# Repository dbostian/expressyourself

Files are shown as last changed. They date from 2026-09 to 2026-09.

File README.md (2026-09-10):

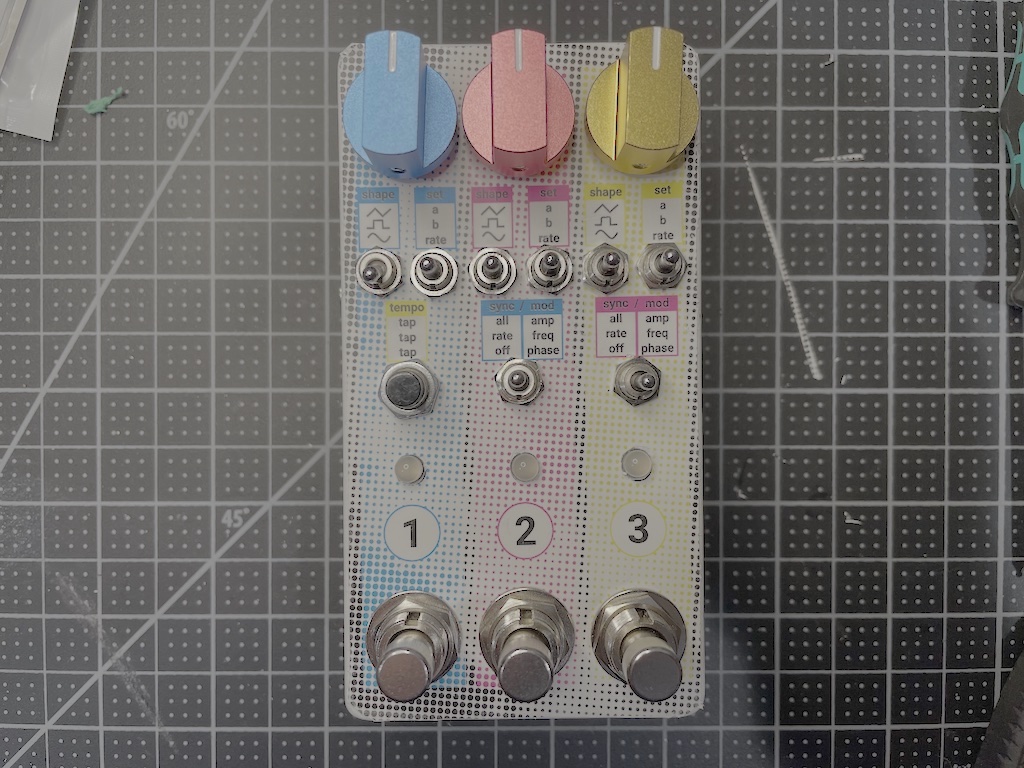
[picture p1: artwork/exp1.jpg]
pedal top view


# express yourself

A DIY triple expression pedal. This pedal was heavily inspired by the Old Blood Noise Endeavors Expression Ramper x3. I wanted to add the ability for the pedal to modulate its own values. It has three expression outputs that can sync with each other, and affect each other in weird ways.

This project is work in progress, and is released on an as-is basis. This repository contains all code, artwork (I printed a vinyl sticker), pcb schematics, gerbers, a bom, as well as 3d printing files (stls, f3d, step) for a 3d printed enclosure. The pedal will fit in a 125b enclosure. The code is working as described below/shown in the videos, but is in a preliminary stage and may contain bugs. In short, use at your own risk.

I am not planning to release detailed build instructions, but if you're a steady hand at soldering, have built a few diy pedals before, ordered custom pcbs, sourced a bom, and have flashed an arduino or two, you should be able to handle this.

Overview Video: https://www.youtube.com/watch?v=8aHI_HfOTI8
Followup Video: https://www.youtube.com/watch?v=umGa9XkKtoM
Part 3: https://www.youtube.com/watch?v=ajVojKqwqVI

## basic usage

The pedal has three sets of expression controls, arranged in columns from left to right. For any exp, you can set the wave **shape** (triangle, square or sine), an **a** value and a **b** value, and a **rate**. The exp will oscillate between **a** and **b** at the **rate** you set, using the selected **shape**. All knob settings are relative - the knob may not match the value when changing the **set** switch, so turning the knob will raise or lower the value accordingly. Pay attention to the LED's brightness, as it reflects the actual value.

Exp 1 can also have its **rate** determined by tap tempo. At most, the last five taps will be used.

To enable an exp's jack, tap the footswitch to enable it. The LED will turn white. Tap again to turn it off. The output of a jack is:
* A if the set switch is on **a**
* B if the set switch is on **b**
* Oscillating if the set switch is on **rate** and the exp is **on**
* A if the set switch is on **rate** and the exp is **off**

You can sync exp2 and exp3 the exp to their left. If **sync** is set to **rate**, the **rate** value will be copied over. If set to **all**, the **a** and **b** values will be copied as well. When syncing (**rate** or **all**), changing the **rate** value will adjust the local rate in multiples of the exp to the left - 1/8, 1/4, 1/2, 1x, 2x, 3x, or 4x.

If you hold down any footswitch while changing the **sync** switch, the exp will enter **mod** mode. The output of the exp to the left will control an aspect of this exp. as follows:
* In **amp** mod mode, the amplitude of the wave will be changed by the output of the exp to the left. **a** and **b** will move apart or closer together about their midpoint. 0% touching, 50% original values, 100% twice as far apart.
* In **freq** mod mode, the frequency of the wave will be changed. The **rate** value will be replaced with the output of exp to the left.
* In **phase** mod mode, the phase of the wave will be offset by the value of the exp to the left. 0%: minus one half wavelength, 50%: no change, 100%: plus one half wavelength.

In **amp** mod mode, the value may exceed the maximum or minimum value of the pedal. In this case, **wavefolding** will occur.

Changing the **sync** switch without holding a footswitch down will turn off the **mod** mode. You can have **sync** mode and **mod** mode active at the same time: move the **sync** switch to the desired **sync** mode, hold the foot switch and select the desired **mod** mode. You cannot have more than one **sync** mode or **mod** mode active at the same time.

If you change the **shape** switch while holding a foot switch, you will enter **random** mode - each time the wave completes a cycle, random values for **a** and **b** will be chosen, using values between the original **a** and **b**.

Future features and code changes:
* One-shot mode. Holding the tap tempo button while selecting shape will put it into one-shot mode. The EXP will move from A to B when the footswitch is tapped, and back from B to A again when tapped again, and so on.
* Hold to pause. While a footswitch is held, the exp's output and progress will be paused. It will resume when the footswitch is released.
* USB Midi?

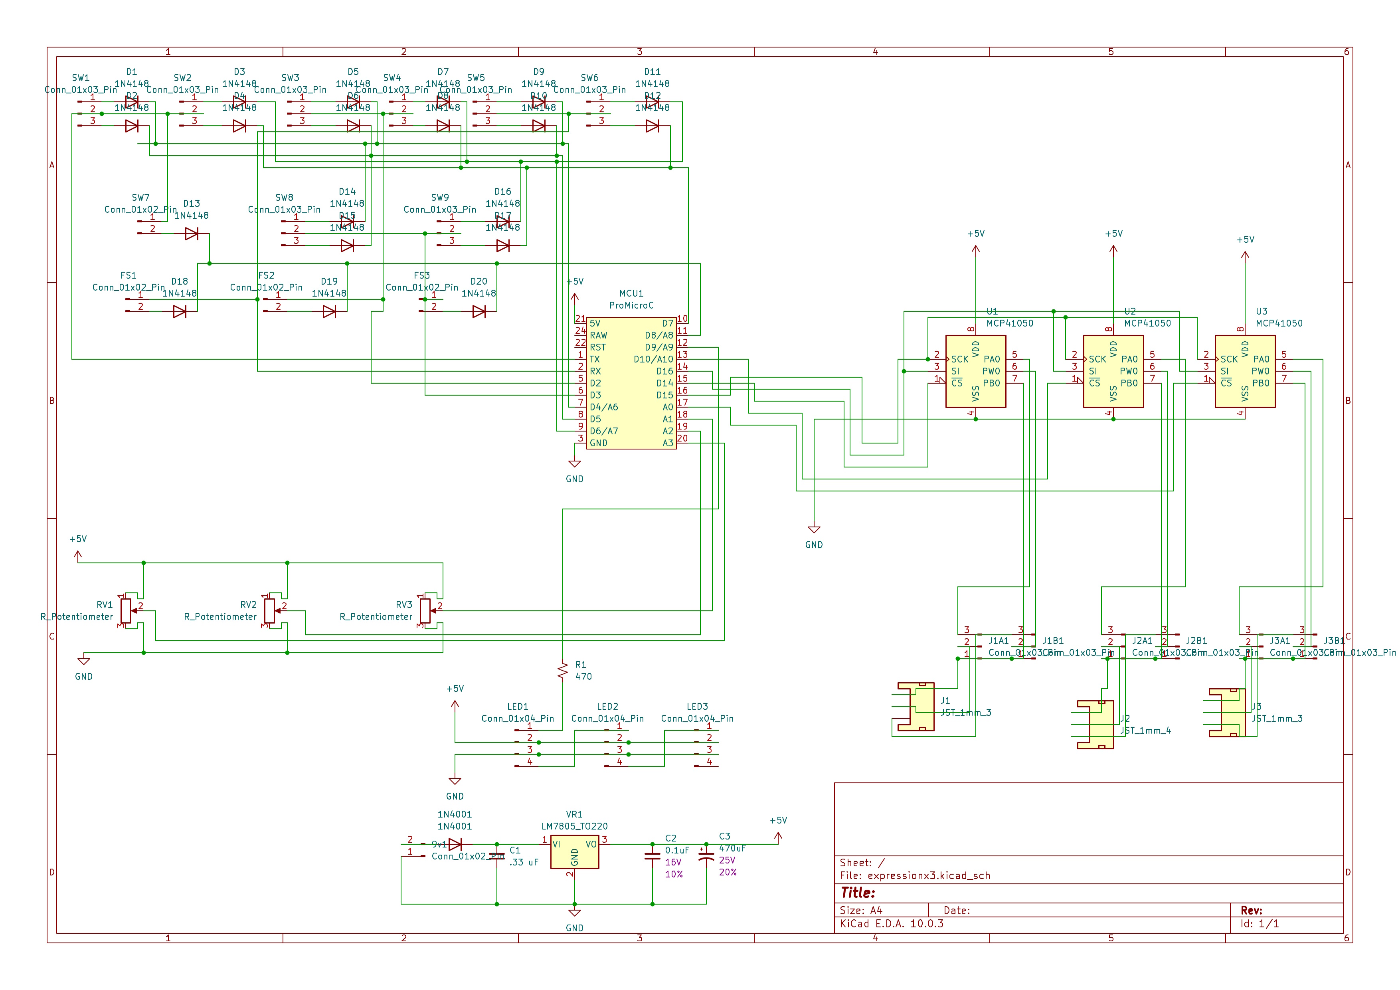
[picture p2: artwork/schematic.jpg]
schematic


## design notes

The schematic and pcb were layed out in KiCad 10.

This circuit uses every IO pin available on the Arduino Pro Micro. To reduce the number of pins used for the switches (many of which have three positions), I used a key matrix with diodes arranged in a 4 x 5 grid. This reduced the pins needed to 9. This is very similar to how a computer keyboard works. For each three-way switch, I can check two positions, and if neither is "pressed," I can tell that it is in the middle position. I'm using the Adafruit_Keypad library for this. They switch matrix handles all of the toggle switches and the momentaries (tap tempo, plus the foot switches). For more information on how a key matrix works (and why this pedal needs so many diodes), check out this article: https://www.dribin.org/dave/keyboard/one_html/

The digipots are controlled using a software SPI. In using every pin available, I ended up using the MISO pin as one of the CS lines. The built in SPI library conflicted with that use case, hence the bit-banging solution.

The artwork is based on a photo of a cloud that I took, converted to halftones. This is color shifted using a CMYK color scheme for the three expression units. I created the art in InkScape.

The 3d print files were for testing hole location, prior to drilling into metal. I've included them for reference. These were designed in Autodesk Fusion.

The code was written in the Arduino IDE. AI use in this project is limited to GitHub copilot commit messages from editing this README file - not for code generation, pcb design, art, or anything else. It certainly didn't help with soldering.

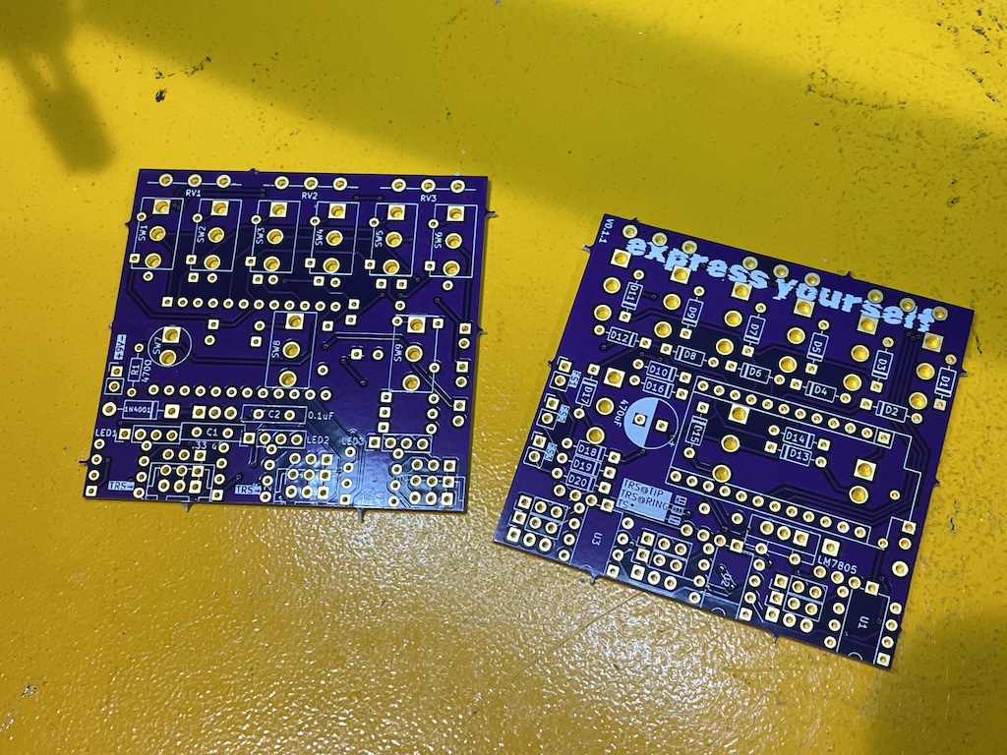
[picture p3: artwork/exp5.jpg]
pcbs

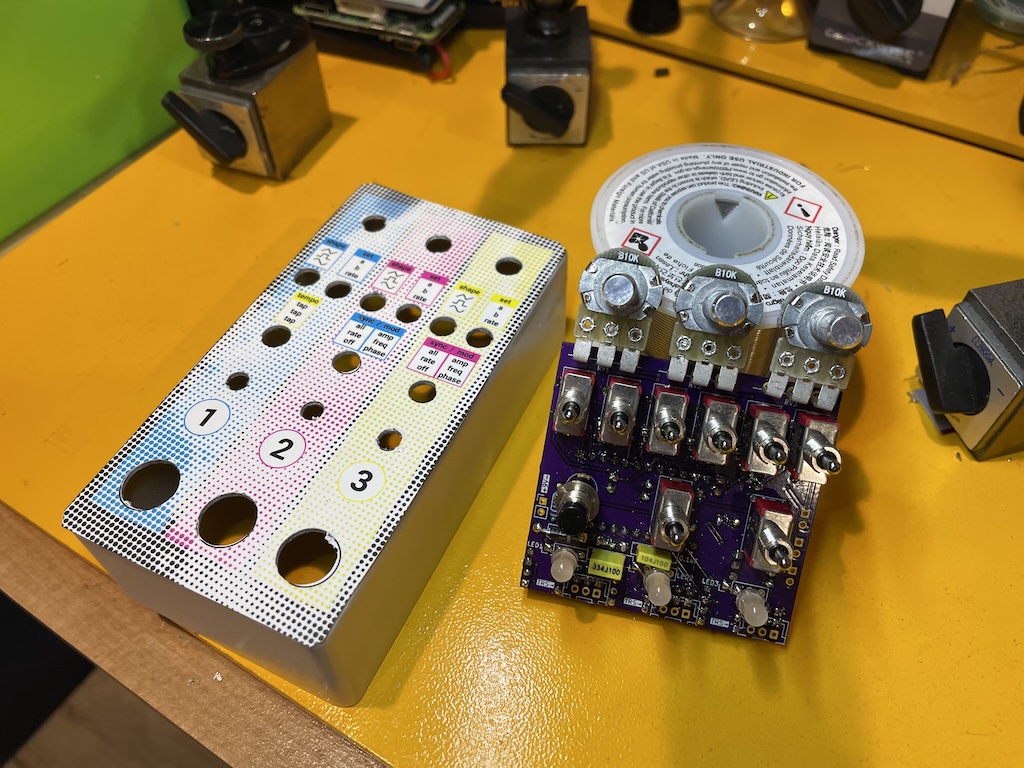
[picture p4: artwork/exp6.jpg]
soldered componentst

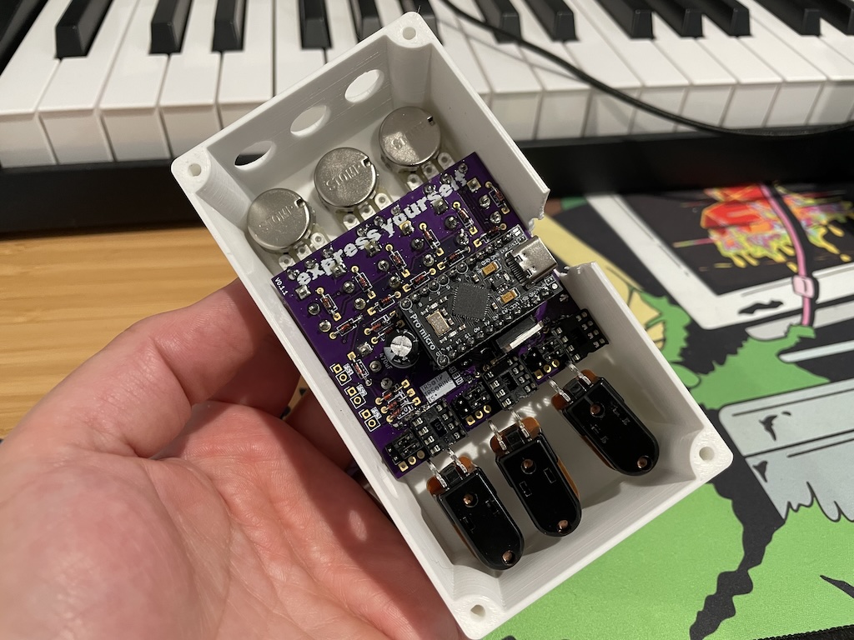
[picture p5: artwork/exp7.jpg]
3d printed enclosure testing


## build notes

The expressionx3.csv contains a fairly complete parts list. Pay attention to the csv, not what is in KiCad.

* Knobs are 20mm apart. I used 19mm diameter Davies style knobs.
* JST connectors did not fit - ignore bom and just use pin header.
* TRS jack choice is important. Others did not fit in the enclosure.
* The pcb is challenging to solder, as I completely disregarded courtyards during design. Plan ahead while soldering. Paying for assembly probably won't work without some updates.
* I installed the pro micro using pin header for clearance. You may want to drill a hole/mill a slot in the side of the enclosure for easy usb cable access, especially if you are planning on experimenting with your own code.
* You may need to bend some terminals during assembly to get everything to fit inside. I needed this for the foot switches.
* You might need to use other sized digipots from the MCP41xx series (bigger/smaller than 50k), depending on what you are plugging them into.
* Someone suggested I flip the outer two foot switches around to make it possible to hit the center switch with normal sized toes.

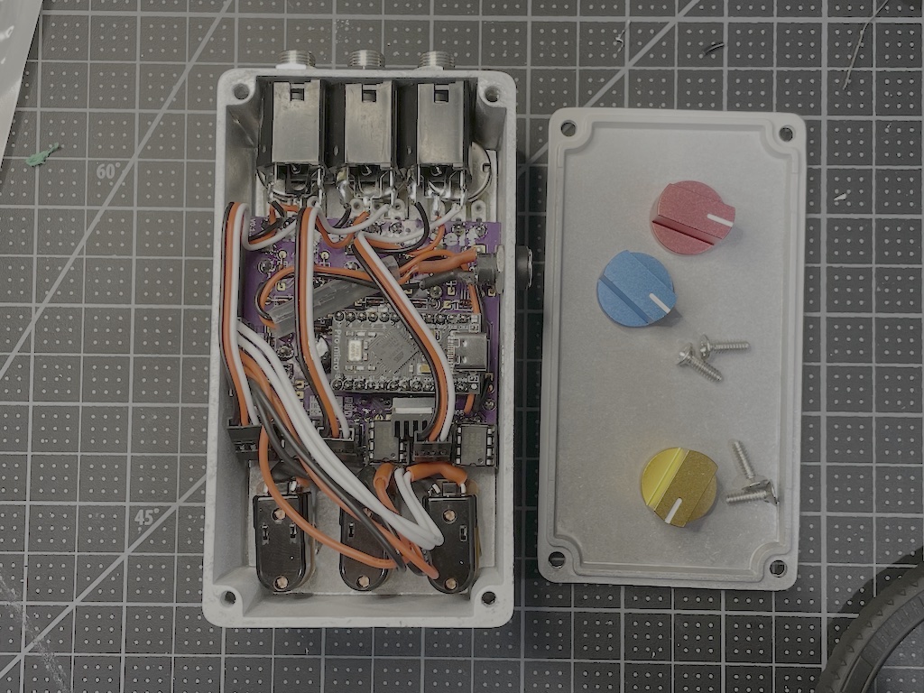
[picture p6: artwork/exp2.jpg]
pedal gutshot

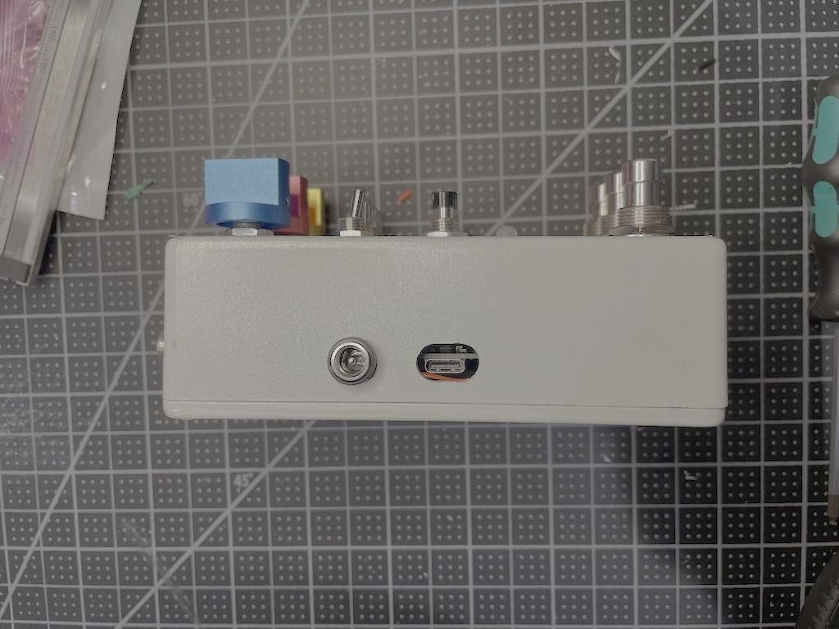
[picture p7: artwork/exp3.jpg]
pedal side view

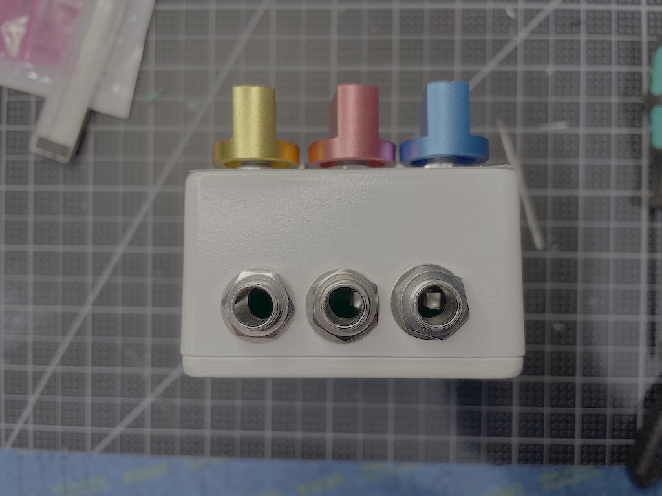
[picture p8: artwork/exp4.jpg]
pedal top


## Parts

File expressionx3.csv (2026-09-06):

Reference | Qty | Value | Notes | Datasheet / Link
1N4001 | 1 | 1N4001 | Chosen over a 1N5817 because of higher voltage drop | http://www.vishay.com/docs/88503/1n4001.pdf
9v1,FS1,FS2,FS3 | 4 | Conn_01x02_Pin
C1 | 1 | .33 uF | Ceramic
C2 | 1 | 0.1uF | Ceramic | https://cdn.sparkfun.com/assets/8/a/4/a/5/Kemet_Capacitor_Datasheet.pdf
C3 | 1 | 470uF | Electrolytic | https://www.nichicon.co.jp/english/series_items/catalog_pdf/e-uud.pdf
D1,D2,D3,D4,D5,D6,D7,D8,D9,D10,D11,D12,D13,D14,D15,D16,D17,D18,D19,D20 | 20 | 1N4148 | Used for switch matrix | https://assets.nexperia.com/documents/data-sheet/1N4148_1N4448.pdf
J1,J3 | 2 | JST_1mm_3 | Use pin header instead
J1A1,J1B1,J2A1,J2B1,J3A1,J3B1 | 6 | Conn_01x03_Pin | See pcb for jumper arrangement
J2 | 1 | JST_1mm_4 | Use pin header instead
LED1,LED2,LED3 | 3 | Conn_01x04_Pin | 5mm Neopixels | https://www.adafruit.com/product/1938
MCU1 | 1 | ProMicroC | 5v Pro Micro | https://www.sparkfun.com/products/15795
R1 | 1 | 470 |  | https://www.vishay.com/docs/20035/dcrcwe3.pdf
RV1,RV2,RV3 | 3 | R_Potentiometer | 16mm B10k
SW1,SW2,SW3,SW4,SW5,SW6,SW8,SW9 | 8 | Conn_01x03_Pin | SPDT on-off-on | https://stompboxparts.com/switches/spdt-toggle-switch-on-off-on-solder-lug-short-bat/
SW7 | 1 | Conn_01x02_Pin | Momentary | https://www.sparkfun.com/momentary-button-panel-mount-black.html
U1,U2,U3 | 3 | MCP41050 |  | http://ww1.microchip.com/downloads/en/DeviceDoc/11195c.pdf
VR1 | 1 | LM7805_TO220 |  | https://www.onsemi.cn/PowerSolutions/document/MC7800-D.PDF
 | 1 | 125B | Enclosure
 | 1 | 5.5 x 2.1 Power | Power jack
 | 3 | 1x3 Dupont connectors, F | Connecting output jacks
 | 4 | 1x2 Dupont connectors, F | Connecting foot switches and power
 | 6 | Jumpers | Output mode (TRS @ Tip, TRS @ Ring, TS)
 | 3 | 8 Dip Socket | Removable digipots
 | 2 | 01x12 Pin Header, F | Pro Micro Mounting
 | 3 | Switch | Momentary Moot Switch
 | 3 | Knob | To taste
 | 3 | TRS Jack | Skinny panel mount | https://stompboxparts.com/audio-jacks/1-4-trs-enclosed-jack-panel-mount-skinny-lug/

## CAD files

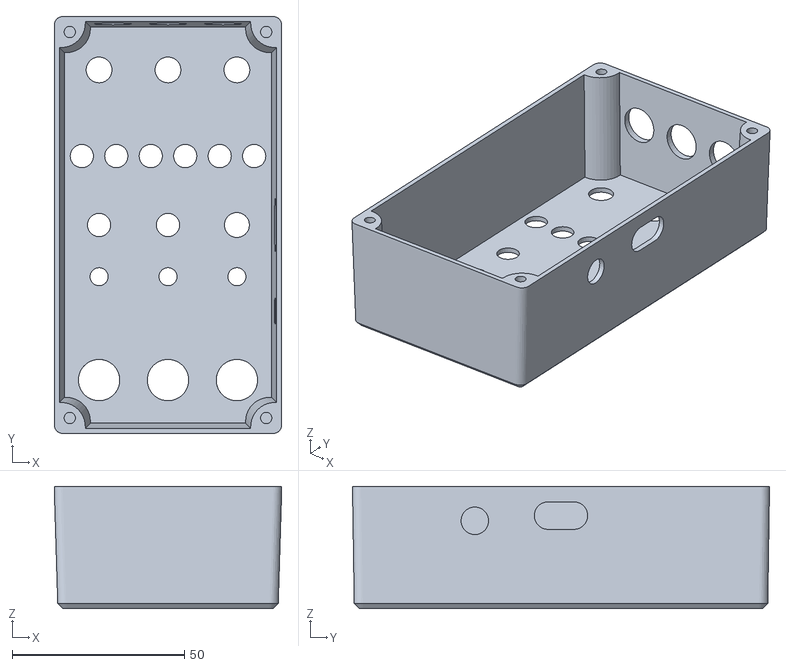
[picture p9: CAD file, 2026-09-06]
3d-printing/Express Yourself - Pedal Enclosure.stl
66.0 x 121.0 x 35.5

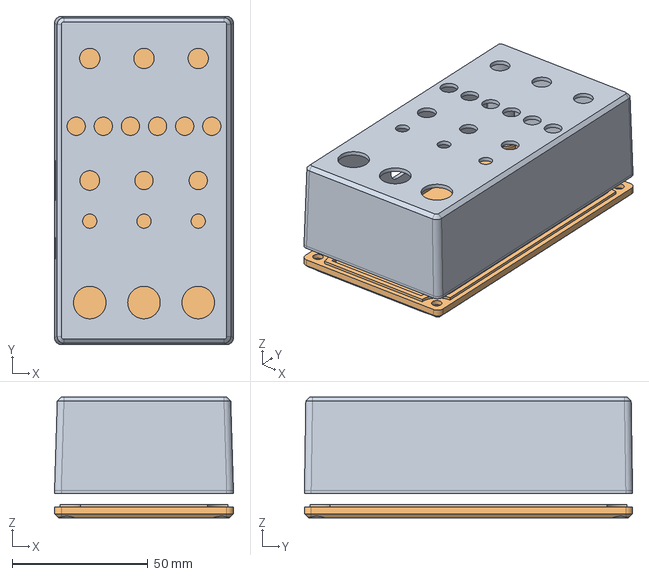
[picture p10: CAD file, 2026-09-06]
3d-printing/Express Yourself.step
66.0 x 121.0 x 44.5 mm

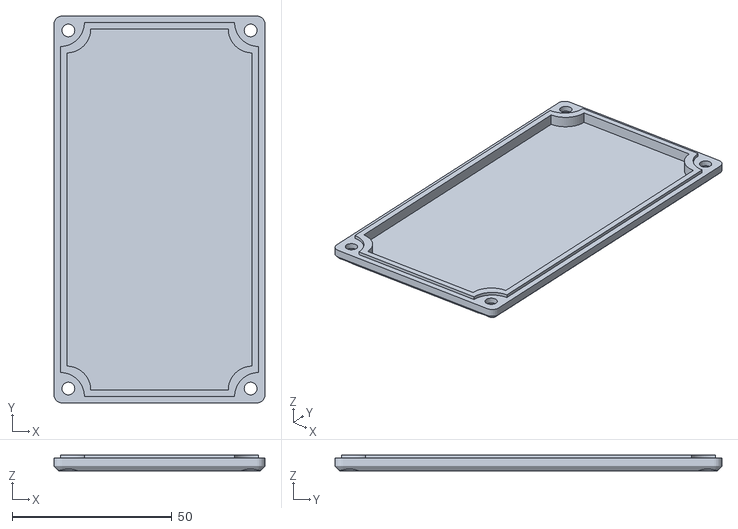
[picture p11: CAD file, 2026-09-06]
3d-printing/Express Yourself - Pedal Base.stl
66.0 x 121.0 x 5.00

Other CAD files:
3d-printing/Express Yourself.f3d

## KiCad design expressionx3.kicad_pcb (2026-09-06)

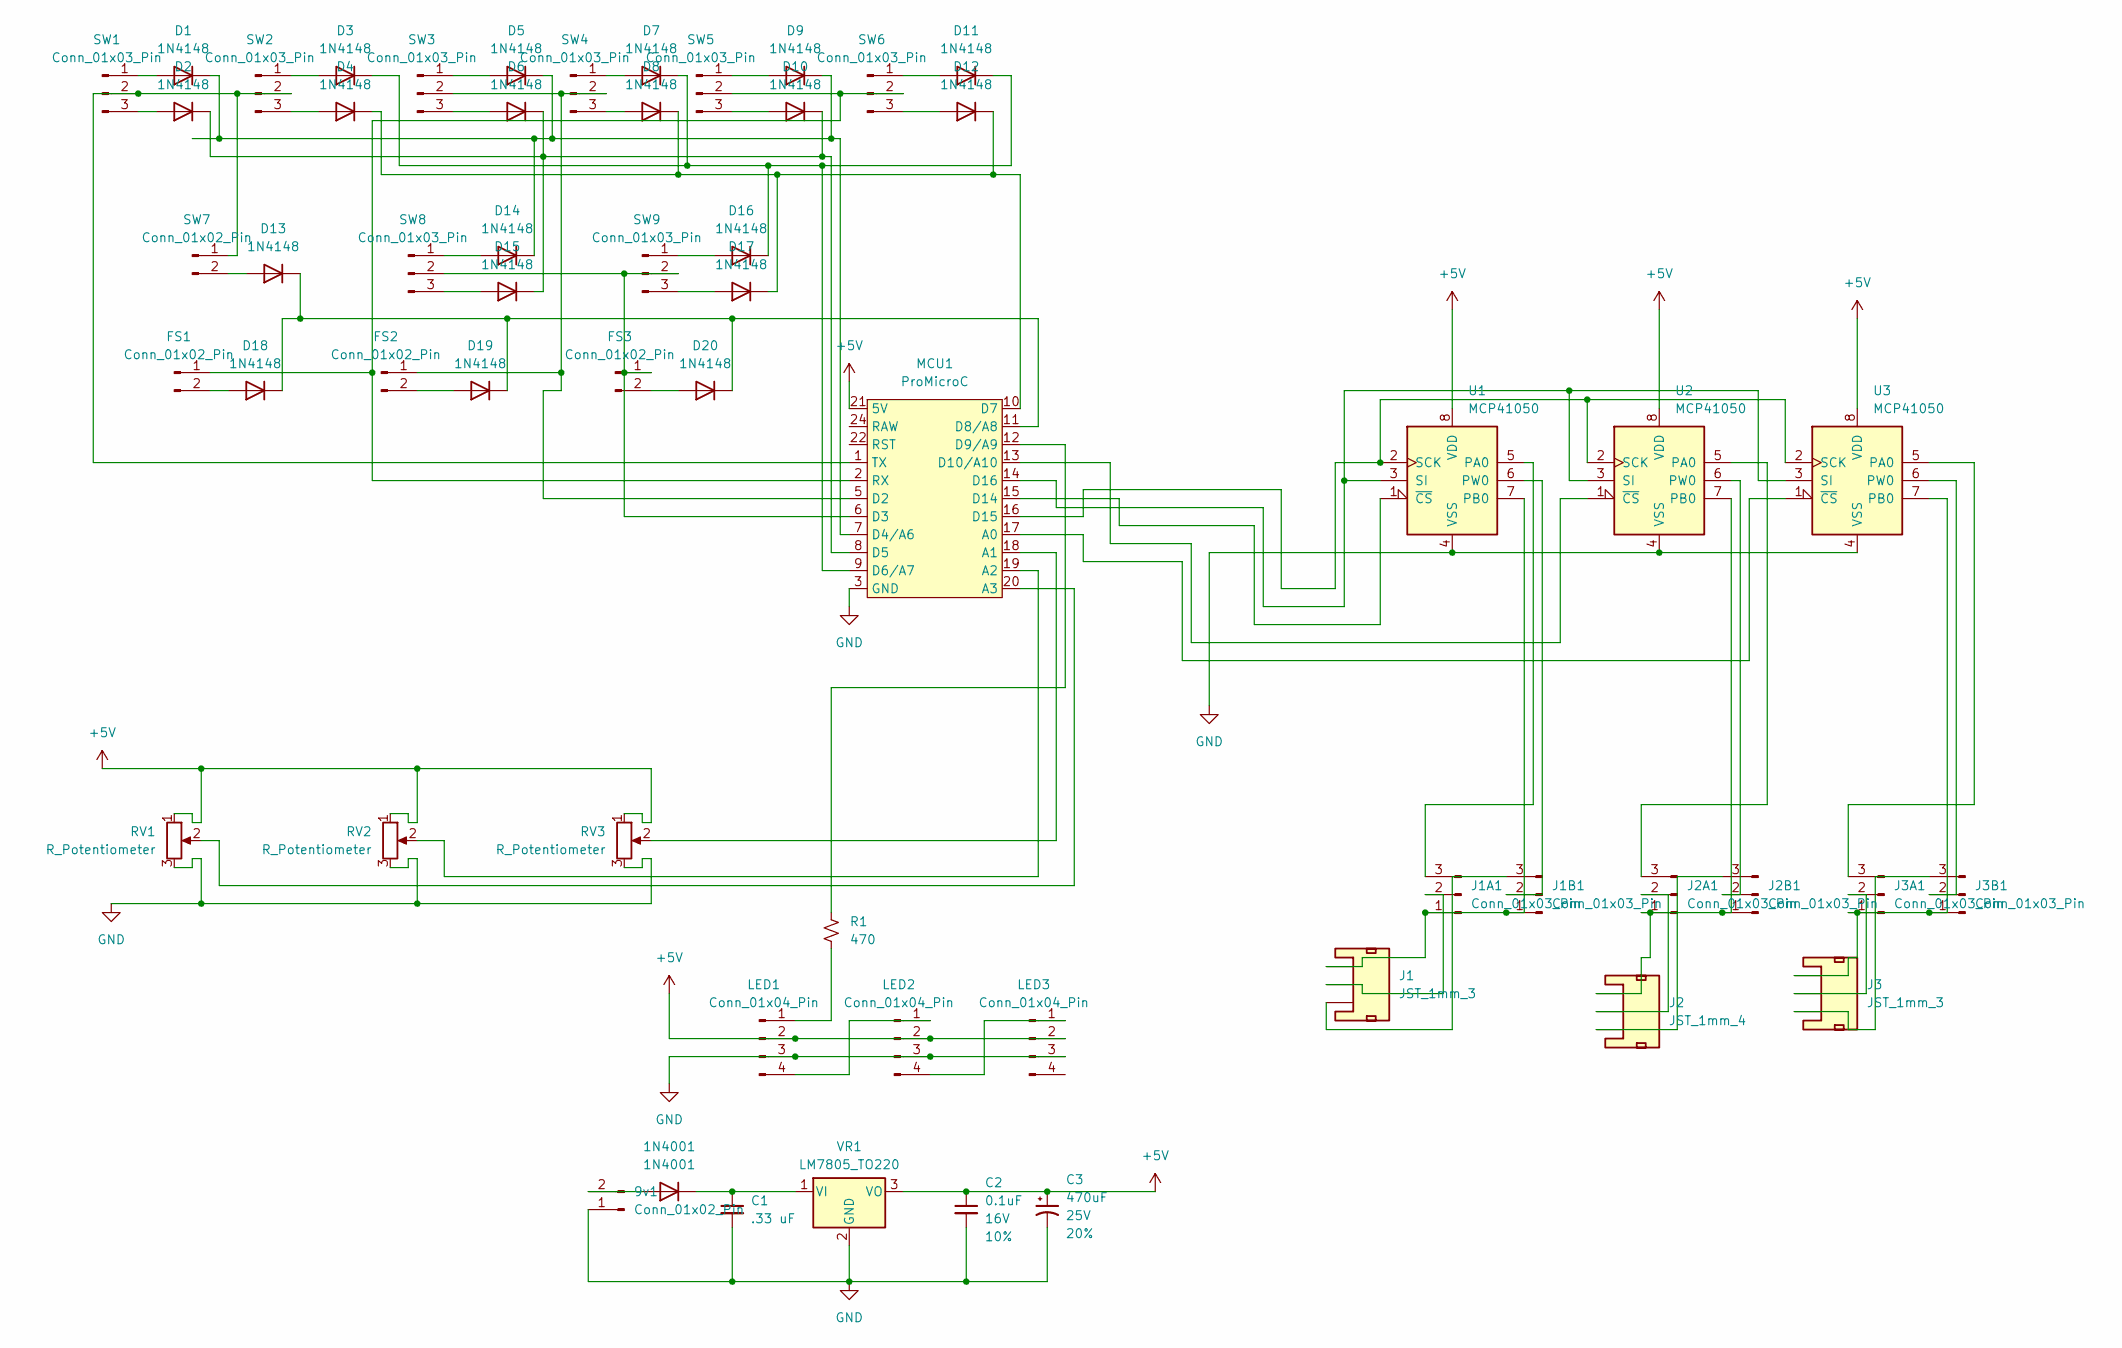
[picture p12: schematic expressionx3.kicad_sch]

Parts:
1N4001: 1N4001; D_DO-41_SOD81_P10.16mm_Horizontal
9v1: Conn_01x02_Pin; PinHeader_1x02_P2.54mm_Vertical
C1: .33 uF; C_Disc_D10.0mm_W2.5mm_P5.00mm
C2: 0.1uF; C_Disc_D10.0mm_W2.5mm_P5.00mm; Voltage 16V; Tolerance 10%
C3: 470uF; CP_Radial_D8.0mm_P3.50mm; Voltage 25V; Tolerance 20%
D1, D2, D3, D4, D5, D6, D7, D8, D9, D10, D11, D12, D13, D14, D15, D16, D17, D18, D19, D20: 1N4148; D_DO-35_SOD27_P7.62mm_Horizontal
FS1, FS2, FS3: Conn_01x02_Pin; PinHeader_1x02_P2.54mm_Vertical
J1, J3: JST_1mm_3; JST_XH_B3B-XH-A_1x03_P2.50mm_Vertical
J1A1, J1B1, J2A1, J2B1, J3A1, J3B1: Conn_01x03_Pin; PinHeader_1x03_P2.54mm_Vertical
J2: JST_1mm_4; JST_XH_B3B-XH-A_1x03_P2.50mm_Vertical
LED1, LED2, LED3: Conn_01x04_Pin; PinHeader_1x04_P2.54mm_Vertical
MCU1: ProMicroC; Sparkfun_Pro_Micro
R1: 470; R_Axial_DIN0204_L3.6mm_D1.6mm_P7.62mm_Horizontal
RV1, RV2, RV3: R_Potentiometer; Potentiometer_Piher_T-16L_Single_Vertical_Hole
SW1, SW2, SW3, SW4, SW5, SW6, SW8, SW9: Conn_01x03_Pin; SPDT
SW7: Conn_01x02_Pin; SPST
U1, U2, U3: MCP41050; DIP-8_W7.62mm
VR1: LM7805_TO220; TO-220-3_Vertical

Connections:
+5V: C2.1, C3.1, LED1.2, LED2.2, LED3.2, MCU1.21 (5V), RV1.1, RV2.1, RV3.1, U1.8 (VDD), U2.8 (VDD), U3.8 (VDD), VR1.3 (VO)
GND: 9v1.1, C1.2, C2.2, C3.2, LED1.3, LED2.3, LED3.3, MCU1.3 (GND), MCU1.4 (GND), MCU1.23 (GND), RV1.3, RV2.3, RV3.3, U1.4 (VSS), U2.4 (VSS), U3.4 (VSS), VR1.2 (GND)
unnamed: 1N4001.2 (A), 9v1.2
unnamed: 1N4001.1 (K), C1.1, VR1.1 (VI)
unnamed: D1.2 (A), SW1.1
unnamed: D1.1 (K), D5.1 (K), D9.1 (K), D14.1 (K), MCU1.7 (D4/A6)
unnamed: D2.2 (A), SW1.3
unnamed: D3.2 (A), SW2.1
unnamed: D4.2 (A), SW2.3
unnamed: D5.2 (A), SW3.1
unnamed: D6.2 (A), SW3.3
unnamed: D7.2 (A), SW4.1
unnamed: D8.2 (A), SW4.3
unnamed: D9.2 (A), SW5.1
unnamed: D10.2 (A), SW5.3
unnamed: D2.1 (K), D6.1 (K), D10.1 (K), D15.1 (K), MCU1.8 (D5)
unnamed: D11.2 (A), SW6.1
unnamed: D3.1 (K), D7.1 (K), D11.1 (K), D16.1 (K), MCU1.9 (D6/A7)
unnamed: D12.2 (A), SW6.3
unnamed: D4.1 (K), D8.1 (K), D12.1 (K), D17.1 (K), MCU1.10 (D7)
unnamed: D13.2 (A), SW7.2
unnamed: D13.1 (K), D18.1 (K), D19.1 (K), D20.1 (K), MCU1.11 (D8/A8)
unnamed: D14.2 (A), SW8.1
unnamed: D15.2 (A), SW8.3
unnamed: D16.2 (A), SW9.1
unnamed: D17.2 (A), SW9.3
unnamed: D18.2 (A), FS1.2
unnamed: D19.2 (A), FS2.2
unnamed: D20.2 (A), FS3.2
unnamed: FS1.1, MCU1.2 (RX), SW5.2, SW6.2
unnamed: FS2.1, MCU1.5 (D2), SW3.2, SW4.2
unnamed: FS3.1, MCU1.6 (D3), SW8.2, SW9.2
unnamed: J1.1, J1A1.1, J1B1.1, U1.7 (PB0)
unnamed: J1.2, J1A1.2
unnamed: J1A1.3, U1.5 (PA0)
unnamed: J1B1.2, U1.6 (PW0)
unnamed: J1.3, J1B1.3
unnamed: J2.1, J2A1.1, J2B1.1, U2.7 (PB0)
unnamed: J2.2, J2A1.2
unnamed: J2A1.3, U2.5 (PA0)
unnamed: J2B1.2, U2.6 (PW0)
unnamed: J2.3, J2B1.3
unnamed: J3.1, J3A1.1, J3B1.1, U3.7 (PB0)
unnamed: J3.2, J3A1.2
unnamed: J3A1.3, U3.5 (PA0)
unnamed: J3B1.2, U3.6 (PW0)
unnamed: J3.3, J3B1.3
unnamed: LED1.1, R1.1
unnamed: LED1.4, LED2.1
unnamed: LED2.4, LED3.1
unnamed: MCU1.17 (A0), U3.1 (~CS)
unnamed: MCU1.18 (A1), RV3.2
unnamed: MCU1.19 (A2), RV2.2
unnamed: MCU1.20 (A3), RV1.2
unnamed: MCU1.12 (D9/A9), R1.2
unnamed: MCU1.13 (D10/A10), U2.1 (~CS)
unnamed: MCU1.15 (D14), U1.1 (~CS)
unnamed: MCU1.16 (D15), U1.2 (SCK), U2.2 (SCK), U3.2 (SCK)
unnamed: MCU1.14 (D16), U1.3 (SI), U2.3 (SI), U3.3 (SI)
unnamed: MCU1.1 (TX), SW1.2, SW2.2, SW7.1

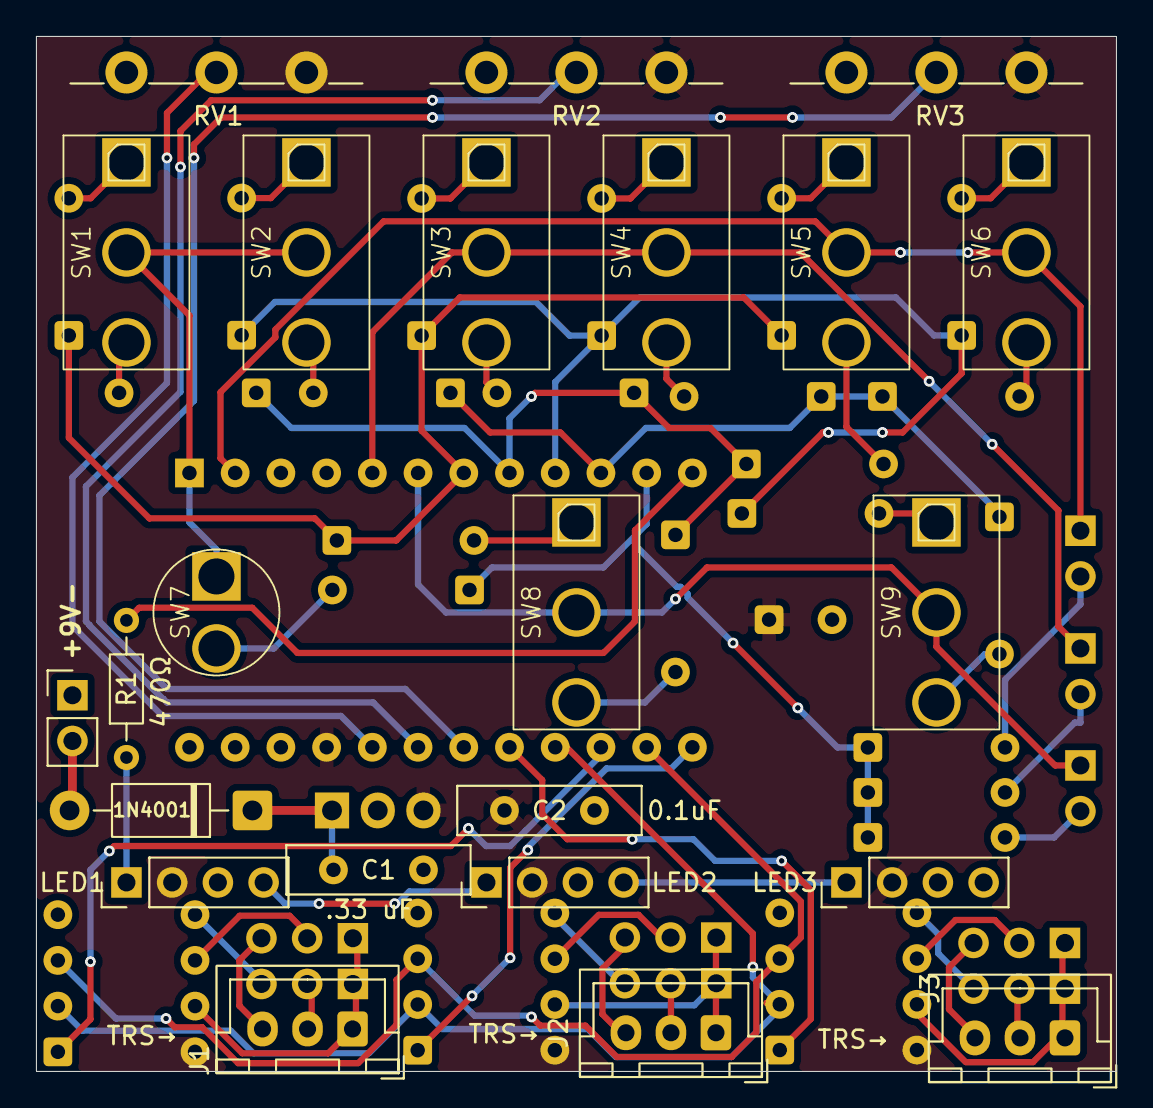
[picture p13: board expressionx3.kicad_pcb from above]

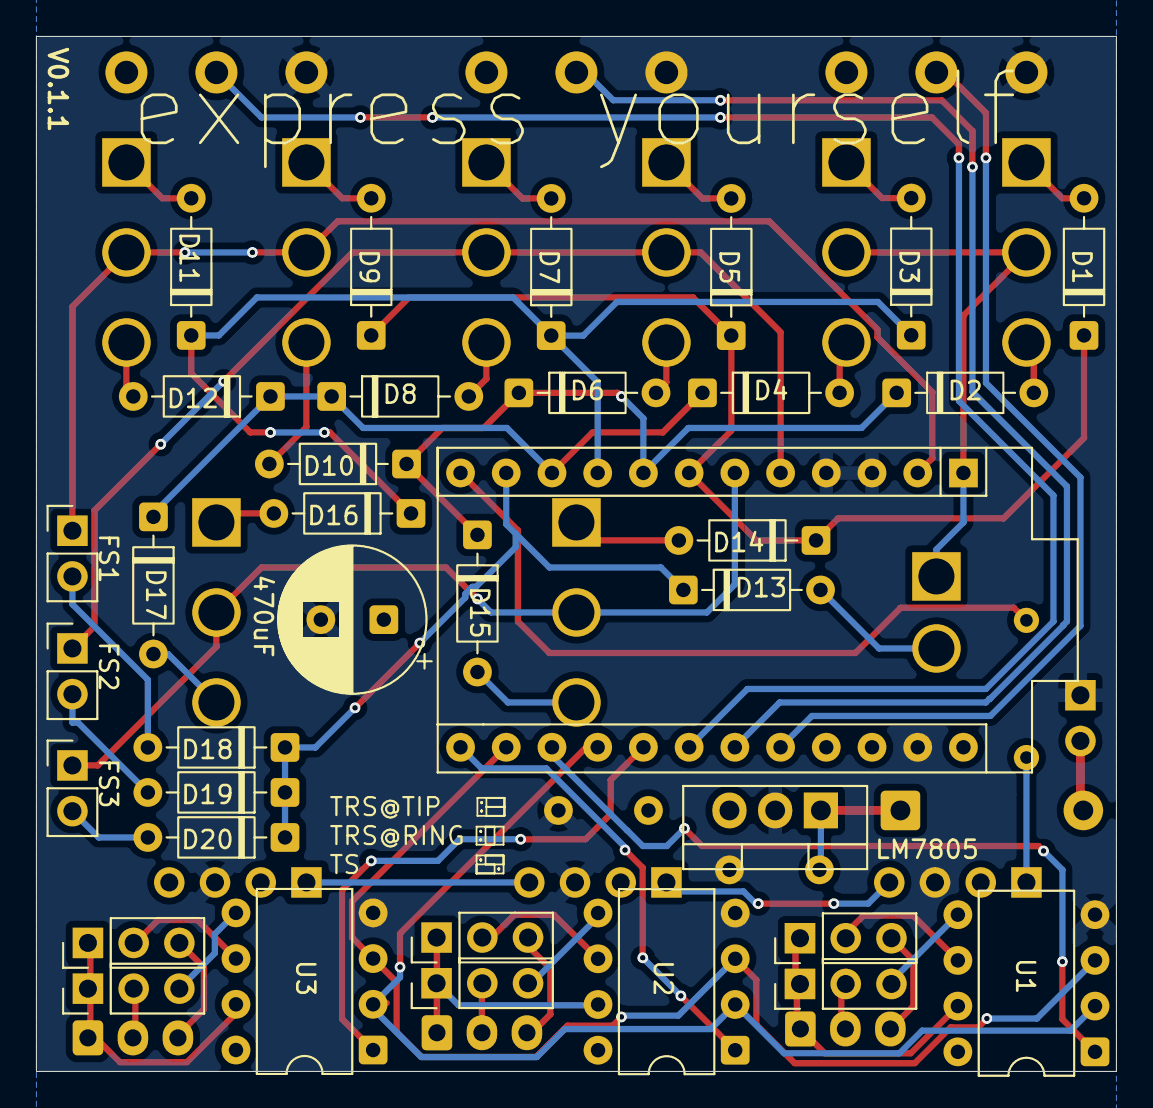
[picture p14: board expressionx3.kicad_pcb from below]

Board: 2 copper layers, 60.0 x 57.5 mm, 58 parts (35 on the bottom side), 60 nets.

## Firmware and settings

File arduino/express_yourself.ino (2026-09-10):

#include "Adafruit_Keypad.h"
#include <Adafruit_NeoPixel.h>

#define SYNC_ALL  0
#define SYNC_RATE 1
#define SYNC_OFF  2

#define MOD_AMP   0
#define MOD_FREQ  1
#define MOD_PHASE 2
#define MOD_OFF   3

#define TRIANGLE  0
#define SQUARE    1
#define SINE      2

#define SET_A     0
#define SET_B     1
#define SET_RATE  2


#define RATEMIN   60000L // 1 bpm (cycle every minute) - slowest rate 
#define RATEMID   1000L  // 60 bpm - when knob is at 12:00
#define RATEMAX   60L    // 1000 bpm (~16.67 beats per second)

#define DIGIPOTMIN 10     // keep the wiper away from the end to protect against high currents
#define DIGIPOTMAX 246    // ...both ends. Not sure if either of these is needed, but here to stay on the safe side.

#define DEBOUNCE  5   // ms
#define TAP_TIME  250 // ms

#define KNOBTHRESHOLD 2  // discard changes below this threshold - jitter
#define KNOBDEBOUNCE 200  // how long after a knob stops before engaging jitter protection

// switches
#define ROWS 4
#define COLS 5

char keys[ROWS][COLS] = {
  {'B', 'A', 'D', 'C', 'E'},
  {'O', 'N', 'Q', 'P', 'F'},
  {'H', 'G', 'J', 'I', 'M'},
  {'L', 'K', 'S', 'R', 'T'}
};

byte colPins[COLS] = {4, 5, 6, 7, 8}; // connect to the row pinouts of the keypad
byte rowPins[ROWS] = {1, 0, 2, 3}; // connect to the column pinouts of the keypad

Adafruit_Keypad switches = Adafruit_Keypad( makeKeymap(keys), rowPins, colPins, ROWS, COLS);

// knobs
#define KNOBPIN1 21
#define KNOBPIN2 20
#define KNOBPIN3 19

byte knobs[3] = {KNOBPIN1, KNOBPIN2, KNOBPIN3};

// digpots
#define DATA    16
#define SCLK    15
#define CS1     14
#define CS2     10
#define CS3     18

byte potpins[3] = {CS1, CS2, CS3};

int vals[3] = {0, 0, 0};
int vals2[3] = {0, 0, 0};  // used to show rate when exp off

// neopixels
#define LED_PIN     9
#define LED_COUNT   3
Adafruit_NeoPixel strip(LED_COUNT, LED_PIN, NEO_RGB + NEO_KHZ800);


// pedal state

unsigned long edges[4] = {0, 0, 0, 0}; // time of last depress (now/millis)
char momentaries[4] = {'F', 'M', 'T', 'E'};  // footswitches 0 indexed, tempo = 3
byte holds[4] = {0, 0, 0, 0}; // is this switch being held down? // same index as momentaries, tempo = 3

// input positions
int shape[3] = {0, 0, 0};
int set[3] = {0, 0, 0};
int sync[3] = {SYNC_OFF, SYNC_OFF, SYNC_OFF};
int knob[3] = {0, 0, 0}; // current knob positions
int knobtempvals[3] = {0, 0, 0}; // temporary knob positions
bool knobmoving[3] = {0, 0, 0}; // is the knob 
unsigned long knobtimers[3] = {0, 0, 0}; // last time the knob changed

// calculated values
byte exps[3] = {0, 0, 0}; // exps 0 = off, 1 = on

// foot switches
byte fs[3] = {0, 0, 0}; // 0 off, 1 held

// tap tempo (last 5 taps)
#define TEMPOTIMEOUT 5000 // tap tempo timout - stop listening after being idle for 5 seconds
#define TAPS 5
unsigned long tempos[TAPS] = {0, 0, 0, 0, 0};
byte tapcount = 0;
unsigned long lasttap = 0;
unsigned long tapduration = 0;

byte mod[3] = {MOD_OFF, MOD_OFF, MOD_OFF};
bool randoms[3] = {0, 0, 0};  // random mode 0 = off, 1 = on
bool oneshot[3] = {0, 0, 0};  // oneshot mode

int a[3] = {768, 786, 768}; // a values
int b[3] = {256, 256, 256}; // b values
int r[3] = {512, 512, 512}; // rates (wavelength in milliseconds)
float p[3] = {0.0, 0.0, 0.0};

// random values, a-b-a-b-a-b
// extends beyond current wavelength, for use when modulating phase
int rvals[3][6] = {
  {0, 0, 0, 0, 0, 0},
  {0, 0, 0, 0, 0, 0},
  {0, 0, 0, 0, 0, 0}
};

unsigned long starts[3] = {0, 0, 0};  // millis value - when an exp was turned on
unsigned long cyclestarts[3] = {0, 0, 0};  // millis - when an exp's current cycle is started
unsigned long cycleends[3] = {0, 0, 0};  // millis - when an exp's current cycle is expected to end -- used to calculate progress and changing rates
float mults[3] = {0, 0, 0}; // multiplication values - used when multiplication factors change

unsigned long now = 0;


void setup() {
  // put your setup code here, to run once:
  Serial.begin(9600);
  switches.begin();

  pinMode(DATA, OUTPUT);
  pinMode(SCLK, OUTPUT);
  digitalWrite(DATA, LOW);
  digitalWrite(SCLK, LOW);
  for (int i = 0; i < 3; i++) {
    pinMode(potpins[i], OUTPUT);
    digitalWrite(potpins[i], HIGH);
  }

  strip.begin();
  strip.setBrightness(64);
  strip.show();

  // initialize randoms array
  for (int i = 0; i < 3; i++) {
    regenerateRandoms(i, 768, 256);
    regenerateRandoms(i, 768, 256);
    regenerateRandoms(i, 768, 256);
  }

  // while(!Serial);
  // Serial.println("\n\nInitialize Serial Monitor");
  
}

void loop() {
  switches.tick();
  // Not doing anything special for this value overflowing.
  // It's ulikely anyone would leave their pedal on for a month and a half.
  // Sorry if bad things happen to you because of this.

  // This is offset by the slowest rate, multiplied by 1/8 and 1/8 
  // Allows for the start to go back in time. Yes, this does mean the slowest
  // the third exp can operate is just over an hour per cycle.
  now = millis() + RATEMIN * 64;


  readMomentarySwitches();
  readToggleSwitches();
  readKnobs();
  
  calculateOutputValues();

  turnDigiPots();
  setLeds();

  Serial.print(0);
  Serial.print(",");
  Serial.print(1024);
  Serial.print(",");
  for (int i = 0; i < 3; i++) {
    Serial.print(vals[i]);
    Serial.print(",");
  }
  Serial.println("");
}

void readMomentarySwitches() {
    // reset tap tempo if idle
    if (now > lasttap + TEMPOTIMEOUT) {
      tapcount = 0;
    }

    for (int i = 0; i < 4; i++) {
      if (switches.isPressed(momentaries[i])) {
        // switch is down
        if (edges[i] == 0) {
          edges[i] = now;
        } else {
          if (edges[i] < now + TAP_TIME) {
            holds[i] = 1;
          }
        }
      } else {
        // switch is up
        // if press < DEBOUNCE time, it's noise - ignore
        // if press > TAP_TIME, it's a hold - no special action
        if (edges[i] != 0 && (edges[i] + DEBOUNCE) < now && (edges[i] + TAP_TIME) > now) {
          // tap detected
          if (i == 3) {
            // tap tempo
            if (now > lasttap + TEMPOTIMEOUT) {
              // first tap in a sequence
              tapcount = 0;
            } else {
              // subsequent taps
              for (int j = 0; j < TAPS - 1; j++) {
                tempos[j] = tempos[j + 1];
              }
              tempos[TAPS - 1] = edges[3] - lasttap; 

              if (tapcount < TAPS) {
                tapcount++;
              }

              unsigned long total = 0;
              for (int j = TAPS - tapcount; j < TAPS; j++) {
                total += tempos[j];
              }
          
              tapduration = total / tapcount;
            }

            lasttap = edges[i];

          } else {
            // toggle exp state on/off
            if (exps[i] == 0) {

              exps[i] = 1;
              starts[i] = now;
              cyclestarts[i] = now;
            } else {
              exps[i] = 0;
              starts[i] = 0;
            }
          }
        }
        
        edges[i] = 0;
        holds[i] = 0;
      }
    }
}

// do I need to debounce these? is it already done in the keypad library?
void readToggleSwitches() {
  bool anyfsheld = holds[0] || holds[1] || holds[2];
  bool tempoheld = holds[3];

  // shape switches
  byte oldshapes[3] = {shape[0], shape[1], shape[2]};

  byte shapeswitchvalue[3] = {
    checkSwitch('A', 'B'),
    checkSwitch('G', 'H'),
    checkSwitch('N', 'O')
  };
  for (byte i = 0; i < 3; i++) {
    if (shape[i] != shapeswitchvalue[i]) {
      shape[i] = shapeswitchvalue[i]; // transfer value
      oneshot[i] = tempoheld;         // set flag for special modes
      randoms[i] = anyfsheld;         // set flag for special modes
    }
  }

  // set switches
  byte setswitchvalue[3] = {
    checkSwitch('C', 'D'),
    checkSwitch('I', 'J'),
    checkSwitch('P', 'Q')
  };

  for (byte i = 0; i < 3; i++) {
    if (set[i] != setswitchvalue[i]) {
      knobmoving[i] = false;  // stop knob
      knobtimers[i] = 0;  // reset knob moving timer

      set[i] = setswitchvalue[i]; // transfer value
    }
  }

  // sync/mod switches
  byte oldsync[3] = {0, sync[1], sync[2]}; 
  byte oldmod[3] = {0, mod[1], mod[2]};
  byte syncsw[3] = {0, checkSwitch('K', 'L'), checkSwitch('R', 'S')};

  for (byte i = 1; i < 3; i++) {  // starts at 1  
    // if mod off, change if switch doesnt match old sync val
    // if mod not off, change if switch doesn't match old mod val
    if ((oldmod[i] == MOD_OFF && oldsync[i] != syncsw[i]) ||
        (oldmod[i] != MOD_OFF && oldmod[i] != syncsw[i])) {
      if (anyfsheld) {
        mod[i] = syncsw[i]; // fs down - mod
      } else {
        sync[i] = syncsw[i]; // fs up - sync
        mod[i] = MOD_OFF; // switch changed - clear mod flag
      }
    }
  }

}

// turns an on-off-on switch into a 0, 1, or 2
byte checkSwitch(char a, char b) {
  if (switches.isPressed(a)) { return 0; }
  if (switches.isPressed(b)) { return 2; }
  return 1;
}

// potentiometer nonsense

void readKnobs() {
  for (int i = 0; i < 3; i++) {
  
    int knobval = analogRead(knobs[i]);
    bool overthreshold = abs(knobtempvals[i] - knobval) > KNOBTHRESHOLD;

    // soft debounce:
    // ignore small changes in knob values (e.g., jitter/noise), but once the
    // knob starts moving, read continuously until it stops again.
    if (!overthreshold && !knobmoving[i]) {
      continue;
    }

    // check if the knob has stopped moving
    if (!overthreshold) {
        // knob has stopped moving, and has for more than our debounce time
        if (now > knobtimers[i] + KNOBDEBOUNCE) {
          knobmoving[i] = false;
          knobtimers[i] = 0;
          continue;
        }
    } else {
        // update knob timers and knobtempvals
        knobtimers[i] = now;
        knobtempvals[i] = knobval;
    }

    // if we are here, the knob is moving
    if (!knobmoving[i]) {
      knobmoving[i] = true;
      knob[i] = knobval;  // update previous knob val
    }
    
    setVal(i, relativeKnobVal(getVal(i), knobval, knob[i]));

    knob[i] = knobval;  // update previous knob val
  }
}

// relative knobs:
// when switching between a, b, and rate, the knob position and value may not
// match. in this case, the knob should control the value in a relative way -
// e.g., turning the knob to the right raises the value, and turning left
// lowers the value.
int relativeKnobVal(int setting, int knobval, int oldknobval) {
  int change = knobval - oldknobval;
  
  // allow value to catch knob if knob moving away
  if ((knobval > setting && change > 0) ||
      (knobval < setting && change < 0 )) {
    change = min(change * 2, knobval - setting);
  }

  return constrain(setting + change, 0, 1023);
}

// reads appropriate value for given set switch
int getVal(byte i) {
  if (set[i] == 0) {
    return a[i];
  }
  if (set[i] == 1) {
    return b[i];
  }
  if (set[i] == 2) {
    return r[i];
  }
}

// sets appropriate value given set switch
void setVal(byte i, int val) {
   if (set[i] == 0) {
      a[i] = val;
    }
    if (set[i] == 1) {
      b[i] = val;
    }
    if (set[i] == 2) {
      r[i] = val;
      if (i == 0) {
        tapduration = 0;  // if changing the rate knob on the first exp, reset tap tempo
        tapcount = 0;
        lasttap = 0;
      }

    }
}

void calculateOutputValues() {
  for (int i = 0; i < 3; i++) {
    int aa = a[i];
    int bb = b[i];
    int wave[6] = {aa, bb, aa, bb, aa, bb};

    int rr = r[i];
    unsigned long start = cyclestarts[i];
    unsigned long end = cycleends[i];
    byte waveshape = shape[i];
    
    // rate modulation
    // replace rate knob with val of exp to left
    if (i > 0 && mod[i] == MOD_FREQ) {
      rr = vals[i-1];
    }

    // sync == all
    float multiplier = 1.0;
    if (syncAll(i)) {
      for (int j = 0; j < 6; j += 2) {
        wave[j] = a[i-1];
        wave[j+1] = b[i-1];
      }
      
      waveshape = shape[i-1];
      if (syncAll(i-1)) {
        for (int j = 0; j < 6; j += 2) {
          wave[j] = a[i-2];
          wave[j+1] = b[i-2];
        }
        waveshape = shape[i-2];
      }
    }

    // sync == all or rate
    if (syncRate(i)) {
      multiplier = rateMultiplier(rr);  // special treatment of rate knob when sync is on
      if (syncRate(i-1)) {
        if (i == 2 & mod[1] == MOD_FREQ) {
          multiplier = rateMultiplier(vals[1]) * rateMultiplier(rr);  // handling of sync & mod_freq for exp 3
        } else {
          multiplier = rateMultiplier(r[i-1]) * rateMultiplier(rr);  // multiply the previous multiplier if both syncs are on
        }
        rr = r[i-2];
      } else {
        rr = r[i-1];
      }
    }

    mults[i] = multiplier;  // update multiplier

    // unsigned long start = cyclestarts[i];
    long wavelength = calcWavelength(rr) * multiplier;

    if (tapduration != 0) { // tap tempo wavelength takeover
      if (
          (i == 0) ||
          (i == 1 && syncRate(1) ||
          (i == 2 && syncRate(1) && syncRate(2)))
       ) {
        wavelength = tapduration * multiplier;
      }
    }
    
    long prevwavelength = cycleends[i] - cyclestarts[i];
    if (prevwavelength == 0) { //startup fix
      prevwavelength = wavelength;
    } 

    float progress = calcProgress(start, end);
    
    progress = progress - (int) progress; // strip to decimal portion only

    if (wavelength != prevwavelength || cyclestarts[i] == 0) {
      start = now - wavelength * progress;
      end = start + wavelength;
    }

    // past the end of the wavelength - move cyclestart and reset randoms
    if (progress < p[i]) {
      start = getAdjustedStart(start + wavelength, progress, wavelength, i);
      end = start + wavelength;

      regenerateRandoms(i, aa, bb);
    }

    cyclestarts[i] = start;
    cycleends[i] = end;
    p[i] = progress;

    // phase modulation
    // shift progress forward or backward according to val of exp to the left
    // here, progress can below 0.0 and above 1.0
    if (i > 0 && mod[i] == MOD_PHASE) {
      float phasefactor = mapf(vals[i-1], 0, 1023, -0.5, 0.5);
      progress = progress + phasefactor;
    }
    
    if (randoms[i]) {
      for (int j = 0; j < 6; j++) {
        wave[j] = rvals[i][j];
      }
    }

    // amplitude modulation
    // scale a and b about their centerpoint, using output from exp to left
    // down = 0x, centered = 1x, up = 2x
    if (i > 0 && mod[i] == MOD_AMP) {
      int center = (aa + bb) / 2;
      float ampfactor = mapf(vals[i-1], 0, 1023, 0.0, 2.0);
      if (aa > center) {
        // note ampfactor goes from 0.0 to 2.0, so this can push a and b beyond
        // their original values
        // and beyond the scale of 0-1023
        for (int j = 0; j < 6; j++) {
          wave[j] = mapf(ampfactor, 0.0, 1.0, center, wave[j]);
        }
      } 
    }

    // for (int j = 0; j < 6; j++) {
    //   Serial.print(wave[j]);
    //   Serial.print(",");
    // }

    if (waveshape == TRIANGLE) {
      vals[i] = triangleWave(progress, wave);
    }
    if (waveshape == SQUARE) {
      vals[i] = squareWave(progress, wave);
    }
    if (waveshape == SINE) {
      vals[i] = sineWave(progress, wave);
    }

    vals[i] = waveFold(vals[i]);

  }

  // Serial.println("");
}

void regenerateRandoms(byte i, int aa, int bb) {
  int randomb = 0;
  int randomc = 0;
  if (aa > b) {
    randomb = random(bb, aa);  // calculate new random values
    randomc = random(bb, aa);
  } else {
    randomb = random(aa, bb);  // calculate new random values
    randomc = random(aa, bb);
  }
  
  // move down
  rvals[i][0] = rvals[i][2];
  rvals[i][1] = rvals[i][3];
  rvals[i][2] = rvals[i][4];
  rvals[i][3] = rvals[i][5];

  if (randomc > randomb) {  // set random vals such that c > b
    rvals[i][4] = randomb;
    rvals[i][5] = randomc;
  } else {
    rvals[i][4] = randomc;
    rvals[i][5] = randomb;
  }
}

float calcProgress(unsigned long start, unsigned long end) {
  long wavelength = end - start;
  if (wavelength == 0 || now == start) {
    return 0.0;
  }

  if (now > start) {
    return ((now - start) % wavelength) / (wavelength * 1.0);
  } else {
    return 1.0 - ((start - now) % wavelength) / (wavelength * 1.0);
  }
}


unsigned long getAdjustedStart(unsigned long start, float progress, int wavelength, byte i) {
  // calculate a new start
  unsigned long newstart = start;

  if (!syncRate(i)) {
    return newstart;
  }

  // find previous exp's closest start to newstart
  unsigned long parentstart = cyclestarts[i-1];
  long parentwavelength = cycleends[i-1] - cyclestarts[i-1];
  float mult = mults[i];

  if (mult > 1.0) {
    // this exp has a bigger multiplier than the parent
    // determine how many parent wavelengths fit in this wavelength at the given progress
    // offset parent start by that many parent wavelengths
    long cyclesofar = wavelength * progress;
    long parentcyclecount = floor(cyclesofar / parentwavelength); 
    
    // offset will always be the same or earlier
    return parentstart - parentwavelength * parentcyclecount;

  } else if (mult == 1.0) {
    // this exp has the same multiplier as the parent - just use that value
    return parentstart;
  } else {
    // this exp has a smaller multiplier than the parent
    // determine how many wavelengths fit in the parent's wavelength at the parent's progress
    // offset parentstart by that many wavelengths
    float parentprogress = (now - parentstart) / (parentwavelength * 1.0);  // TODO now - start
    long parentcyclesofar = parentwavelength * parentprogress;
    long childcyclecount = floor(parentcyclesofar / wavelength);

    // offset will always be the same or later
    return parentstart + wavelength * childcyclecount;
  }  
}

int waveFold(int val) {
  int folded = val;
  while (folded < 0 || folded > 1023) {
    if (folded > 1023) {
      folded = 1023 - (folded - 1023);
    }
    if (folded < 0) {
      folded = abs(folded);
    }
  }
  return folded;
}

// is sync set to all?
bool syncAll(byte i) {
  return (i > 0 && sync[i] == SYNC_ALL);
}

// is sync set to all or rate?
bool syncRate(byte i) {
  return (i > 0 && (sync[i] == SYNC_ALL || sync[i] == SYNC_RATE));
}

// sets digipot values
void turnDigiPots() {
  for (int i = 0; i < 3; i++) {
    long val = vals[i];

    // switch state overrides
    if (set[i] == 0 || exps[i] == 0) {
      val = a[i]; // set is in 'A' position -or- exp is off
    }
    if (set[i] == 1) {
      val = b[i]; // set is in 'B' position
    }

    // scale to digipot value
    setPotValue(i, val);
  }
}

void setPotValue(byte i, long val) {
  long outval = map(val, 0, 1023, 0, 255);  // note, if you don't map this to the max digipot value, you get some cool wavefolding effects.

  byte pin = potpins[i];
  digitalWrite(pin, LOW);
  shiftOut(DATA, SCLK, MSBFIRST, 0x11);
  shiftOut(DATA, SCLK, MSBFIRST, outval);
  digitalWrite(pin, HIGH);
}


void setLeds() {
  // set neopixel values
  for (int i = 0; i < 3; i++) {
    int red = map(vals[i], 0, 1023, 0, 255);
    int grn = map(vals[i], 0, 1023, 0, 255);
    int blu = map(vals[i], 0, 1023, 0, 255);

    int aa = map(a[i], 0, 1023, 0, 255);
    int bb = map(b[i], 0, 1023, 0, 255);

    if (set[i] == 0) {    // set is in 'a' position
      strip.setPixelColor(i, aa, 0, 0);
    } else if (set[i] == 1) { // set is in 'b' position
      strip.setPixelColor(i, 0, bb, 0);
    } else {
      if (exps[i] == 1) { // exp is on
        strip.setPixelColor(i, red, grn, blu);  // white
      } else {  // exp is off
        if (mod[i] != MOD_OFF) {  //modulating
          strip.setPixelColor(i, red, 0, blu);  // magenta
        } else if (sync[i] != SYNC_OFF) {       //syncing
          strip.setPixelColor(i, 0, grn, blu);  // cyan
        } else {
          strip.setPixelColor(i, red, grn, 0);  // yellow
        }
      }
    }

  }
  strip.show();
}

// middle of the knob should be 1bpm, so this is two lines of different slope
// ...basically a bad expo knob
long calcWavelength(int rate) {
  long wavelength = 0;
  if (rate >= 0 && rate <= 512) {
    wavelength = map(rate, 0L, 512L, RATEMIN, RATEMID);
  } else if (rate > 512 && rate <= 1023) {
    wavelength = map(rate, 512L, 1023L, RATEMID, RATEMAX);
  }

  if (wavelength > RATEMIN) {
    return RATEMIN;
  }
  if (wavelength < RATEMAX) {
    return RATEMAX;
  }
  return wavelength;
}

// progress = value between -0.5 and 1.5, wave is a series of values a-b-a-b-a-b (or randomized)
float sineWave(float progress, int wave[]) {
  // yes, the sine wave is a cosine, as we want to go from a at 0 to b at 50% to c at 100%
  float cosrads = cos(progress * 2 * PI);

  int output = 0;

  if (progress <= 0.0) {
    output = mapf(cosrads, -1.0, 1.0, wave[1], wave[2]);
  } else if (progress <= 0.5) {
    output = mapf(cosrads, 1.0, -1.0, wave[2], wave[3]);
  } else if (progress <= 1.0) {
    output = mapf(cosrads, -1.0, 1.0, wave[3], wave[4]);
  } else {
    output = mapf(cosrads, 1.0, -1.0, wave[4], wave[5]);
  }

  return output;
}

// progress = value between -0.5 and 1.5, wave is a series of values a-b-a-b-a-b (or randomized)
float triangleWave(float progress, int wave[]) {
  int output = 0;

  if (progress <= 0.0) {
    output = mapf(progress, -0.5, 0.0, wave[1], wave[2]);
  } else if (progress <= 0.5) {
    output = mapf(progress, 0.0, 0.5, wave[2], wave[3]);
  } else if (progress <= 1.0) {
    output = mapf(progress, 0.5, 1.0, wave[3], wave[4]);
  } else {
    output = mapf(progress, 1.0, 1.5, wave[4], wave[5]);
  }
  
  return output;
}

// progress = value between -0.5 and 1.5, wave is a series of values a-b-a-b-a-b (or randomized)
float squareWave(float progress, int wave[]) {
  int output = 0;

  if (progress <= 0.0) {
    output = wave[1] * 1.0;
  } else if (progress <= 0.5) {
    output = wave[2] * 1.0;
  } else if (progress <= 1.0) {
    output = wave[3] * 1.0;
  } else {
    output = wave[4] * 1.0;
  }

  return output;
}
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

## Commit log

2026-09-06 Updated bom
    [expressionx3.csv]
2026-09-06 More bom
    [expressionx3.csv]
2026-09-06 Revise build notes for clarity and important updates
    Updated build notes for clarity and added important information about TRS jack fit and assembly challenges.
2026-09-06 More photos, schematic
2026-09-06 Add images to README for schematic and PCB
    Added images to README for better visual representation.
2026-09-07 Fixed random mode for sine and triangle, added gitignore
    [express_yourself.ino]
2026-09-09 Fixed uneven transitions when adjusting rate
    [express_yourself.ino]
2026-09-09 fixed issue with random vals being calculated multiple times when changing/modulating rate
    [express_yourself.ino]
2026-09-09 Fixed phasefactor from - 1/2 to + 1/2
    [express_yourself.ino]
2026-09-10 modulation + random fix, added wave folding
    [express_yourself.ino]
